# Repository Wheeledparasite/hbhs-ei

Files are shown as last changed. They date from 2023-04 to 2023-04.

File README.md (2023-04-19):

# Huntington Beach High School - Automotive Engineering Club - 2022 Archive
HBHS 2022 Energy Invitational Repo

## Archived repository for 2022 Energy Invitational Competition
The [HBHS Automotive Engineering Club](https://hbhs.bytethug.com/) competed at the 2022 [UCI Energy Invitational](https://vitallink.org/program/energy-invitational/) competition for the first time.

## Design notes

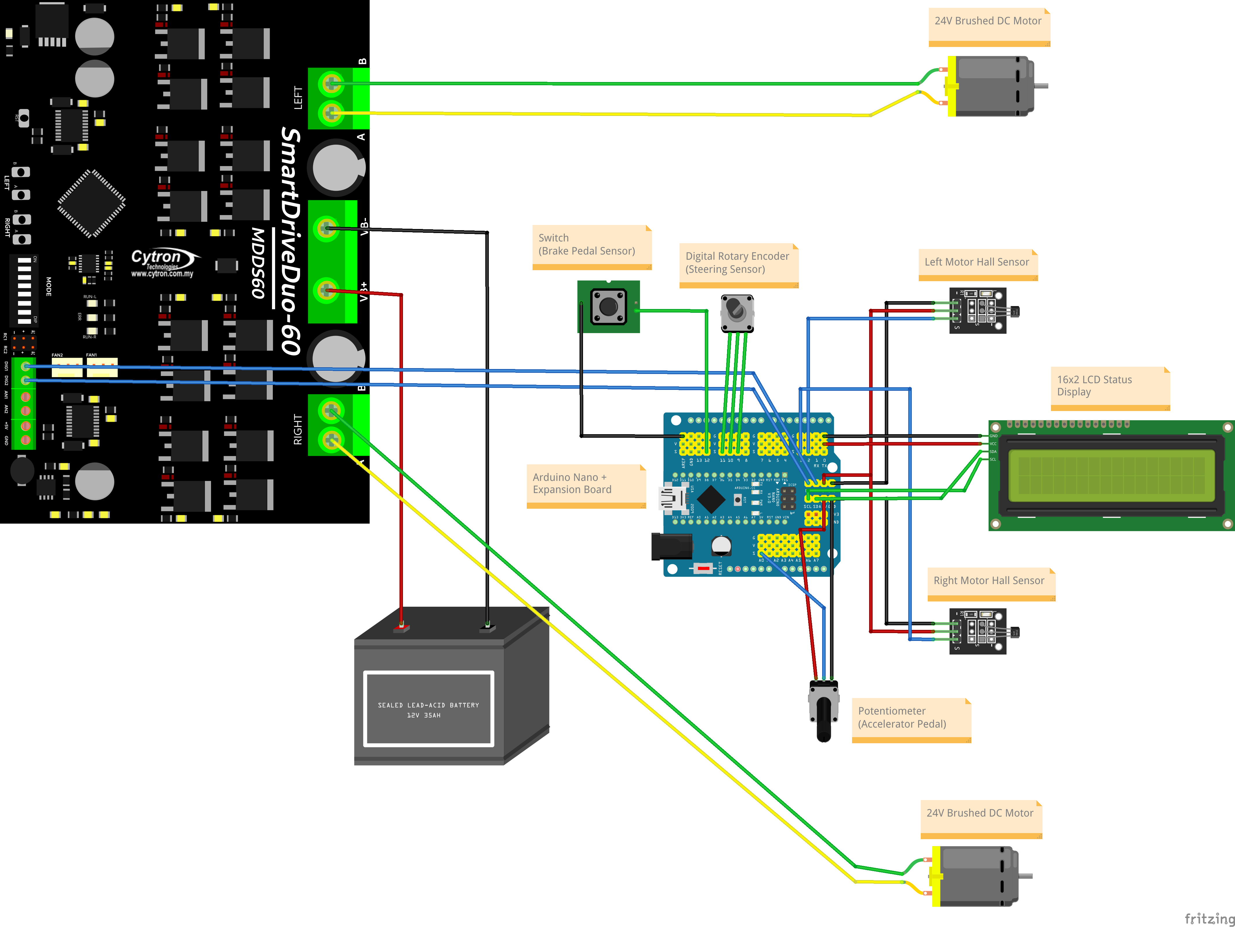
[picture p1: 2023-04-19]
schematics/schematic_v2.png

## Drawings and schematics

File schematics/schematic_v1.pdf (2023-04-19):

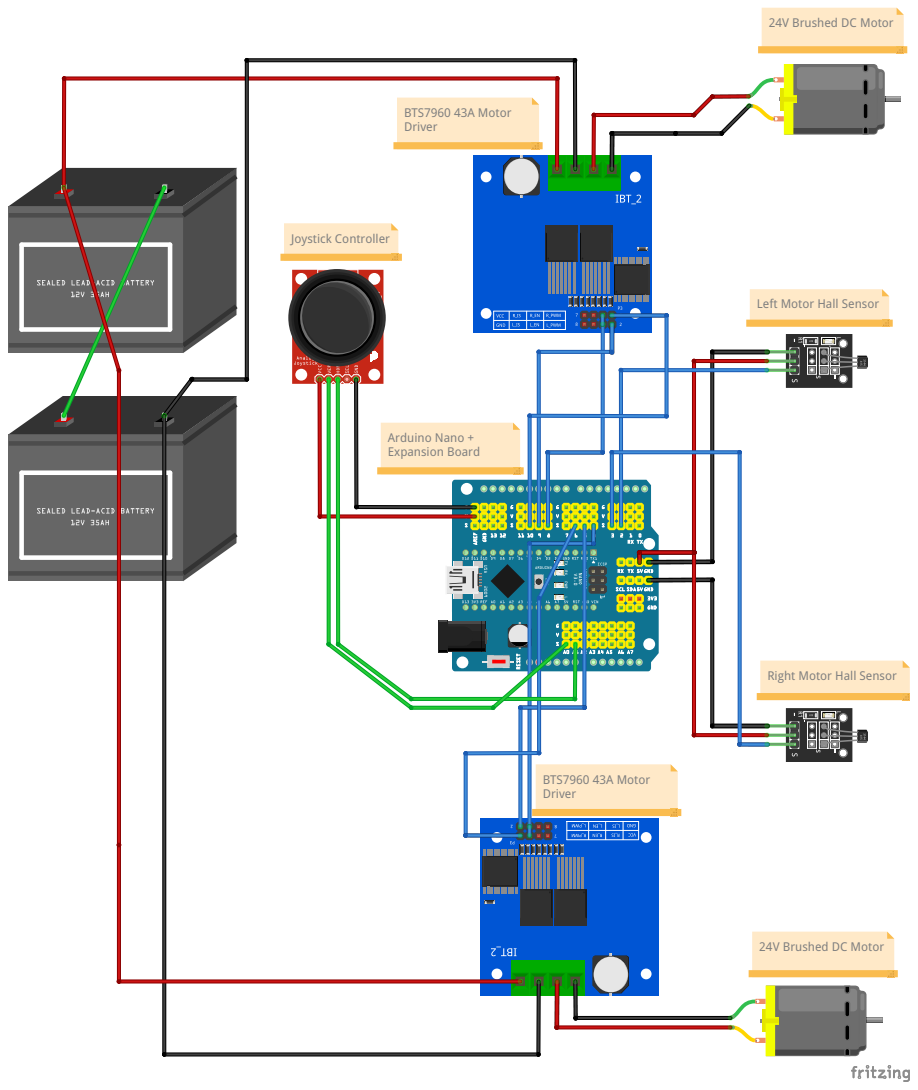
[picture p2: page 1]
BTS7960 43A Motor Driver; Arduino Nano + Expansion Board; Joystick Controller

24V Brushed DC Motor

Left Motor Hall Sensor

Right Motor Hall Sensor

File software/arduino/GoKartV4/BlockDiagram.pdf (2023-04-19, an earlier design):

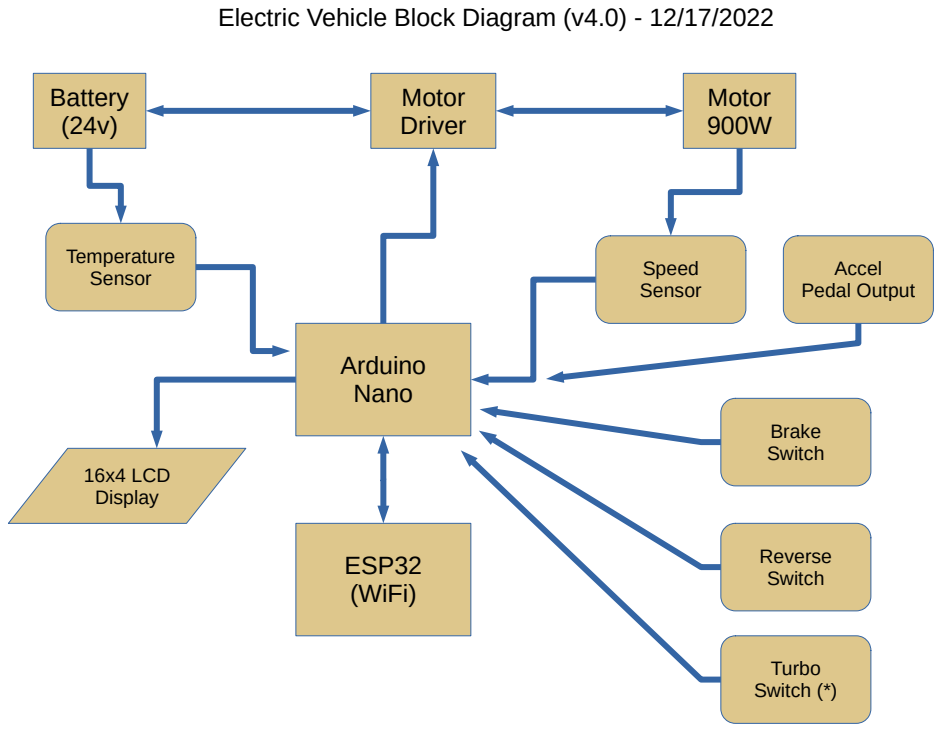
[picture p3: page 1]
Motor; Driver; Battery; Arduino; Nano; 16x4 LCD; Display; Speed; Sensor; Temperature; ESP32 (WiFi); Accel; Pedal Output; Brake; Switch; Reverse; Turbo; Switch (*)

Electric Vehicle Block Diagram (v4.0) - 12/17/2022

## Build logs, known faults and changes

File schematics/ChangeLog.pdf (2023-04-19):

Electronics Changelog

Version 1.0
- 16Mhz Arduino NANO
- 3 Hardware Timers (Timer0, Timer1 and Timer2)
- 1 UART (serial port)
- 6 PWM Pins (8-bit)
- 2 Interrupt Pins (Pin 2 & Pin 3)
- 2 Kb RAM
- 32 Kb Flash ROM
- (2) BTS7960 43A Motor Drivers
- Input from PS2 Style Joystick
- Hall Effect Sensors for wheel encoders (speed sensor)

Limitations of Version 1.0 Hardware
After building the 1.0 electronics test platform, we quickly determined there were some limitations of using such a slow 8-bit processor. First, because each of the BTS7960 motor drivers required 2 PWM signals, we needed a total of 4 PWM outputs. Using 4 PWM pins on the Arduino Nano meant that both TIMER0 and TIMER1 were being used to generate PWM signals and we only had TIMER2 left. We are using Timer2 set to 500ms to average the wheel encoder counts. Also, we have two HALL effect sensors we are using to measure wheel speed, these use up both Interrupt pins, leaving us with no free external interrupt pins in case we want to measure something else using interrupts. Two PID controllers manage motor speed based upon user input and measured speed.

Version 2.0:
- 16Mhz Arduino NANO
- 3 Hardware Timers (Timer0, Timer1 and Timer2)
- 1 UART (serial port)
- 6 PWM Pins (8-bit)
- 2 Interrupt Pins (Pin 2 & Pin 3)
- 2 Kb RAM
- 32 Kb Flash ROM
- (1) Cytron SmartDuo 60A Dual Channel Motor Driver (supports UART)
- Input from Accelerator Pedal + Steering Wheel
- (2) Temperature Sensors
- Hall Effect Sensors for wheel encoders (speed sensor)

Notes on Version 2.0 Hardware
The biggest change to this revision is the change from the generic motor drivers in V1 to the Cytron 60A Dual Driver in V2. This new motor driver allows serial communication (UART), allowing us to free up another TIMER in the Arduino, by removing the need for PWM, which will allow us to smoothly apply acceleration and deceleration, preventing the jerky movements we experienced in Version 1.0.

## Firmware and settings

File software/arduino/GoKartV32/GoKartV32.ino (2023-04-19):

/*
 * Author: Lucas Ruebsamen
 * Date: December 28, 2021
 * 
 * Version 1.1 - Updated Jan 14, 2022
 * Version 1.4 - Updated Feb 9, 2022
 * Version 3.0 - Updated March 16, 2022
 * Version 3.1 - Updated April 20, 2022
 * 
 * Changelog:
 * 1.0 - Original Version using Differential Steering
 * 1.1 - Remove reverse ability
 * 1.2 - Interrupt to count wheel rotation sensors (hall effect sensor)
 * 1.3 - Implement PID motor control
 * 1.4 - 500ms Timer2 interrupt to average wheel encoder counts.
 * 3.0 - Move to Cytron Driver board (serial) and steering encoder
 * 3.1 - Brake on Startup (Safety Feature)
 * 3.2 - Soft Acceleration
 * 
 * Notes: Differential steering control using two BTS7960 motor drivers
 *        driving two 250W Scooter motors.
 * 
 * Differential Steering Library: https://github.com/edumardo/DifferentialSteering
 * LCD Library: https://github.com/mrkaleArduinoLib/LiquidCrystal_I2C
 * PID Lbirary: https://github.com/imax9000/Arduino-PID-Library
 */

// SmartDriveDuo-60 Simplied Serial Mode (115200 baud) DIP SW SETTINGS:
// 11011100

/*
 * Timer0 - used for millis() micros() delay()… and is on pin 5, 6
 * Timer1 - 16bit timer is on pin 9, 10
 * Timer2 - 8bit timer is on pin 3, 11
 * 
 */

#include <Wire.h> 
#include <LiquidCrystal_I2C.h>
//#include "QuickPID.h"
//#include <MsTimer2.h>
//#include "DifferentialSteering.h"
#include <Encoder.h>

//#define PIDCONT

// PWM PINS on NANO: 3,5,6,9,10,11
// INTERRUPT PINS ON NANO: 2,3

// STEERING SENSOR (Rotary Encoder)
const uint8_t STEER_A = 7;
const uint8_t STEER_B = 8;
const uint8_t STEER_SW = 4;

//Pedal sensor pin
const uint8_t PEDAL = A0;

//turbo pin
const uint8_t TURBO = 9;

//power switch
const uint8_t POWER = 6;

//direction switch
const uint8_t DIRSW = 5;

//brake light
const uint8_t BRAKELIGHT = 10;

// differential steering
//const int brakeThreshold = 0;
//const int fPivYLimit = 32;  // 0 - 127 (A greater value will assign more of the joystick's range to pivoting) - default 32
//DifferentialSteering DiffSteer;

// instantiate our objects
LiquidCrystal_I2C lcd(0x27,16,2);  // set the LCD address to 0x27 for a 16 chars and 2 line display
Encoder steerEncoder(STEER_A, STEER_B);

const unsigned int sampleTime = 256;  // LCD UPDATE INTERVAL
const unsigned int accelTime = 500;   // ACCEL UPDATE INTERVAL
unsigned long lastMillis = 0;
unsigned long lastMillisAccel = 0;
volatile uint16_t avgLeft = 0;
volatile uint16_t avgRight = 0;
int pedalPos;
int desiredPedalPos = 0;

// Update Acceleration
void updateAccel()
{
  if (desiredPedalPos < pedalPos) {
    pedalPos = desiredPedalPos;
  } else {
    int diff = ceil( ((float)(desiredPedalPos - pedalPos))*(0.1f) );

    if (pedalPos > 30) {
      diff = 1; // slow down acceleration at top speed.
    }
    pedalPos += diff;
    if (pedalPos > desiredPedalPos) {
      pedalPos = desiredPedalPos;
    }
  }
}

// Run Once - Setup
void setup()
{
  Serial.begin(115200);
  // setup pins for speed sensors
  //pinMode(R_SEN, INPUT);
  //pinMode(L_SEN, INPUT);

  // pin for rotary switch
  pinMode(STEER_SW, INPUT_PULLUP);

  // setup pin for analog accelerator pedal
  pinMode(PEDAL, INPUT);
  pinMode(TURBO, INPUT_PULLUP);

  // setup pin for Power Switch
  pinMode(POWER, INPUT_PULLUP);

  pinMode(DIRSW, INPUT_PULLUP);
  pinMode(BRAKELIGHT, OUTPUT);

  // set initial speed to 0 for motor driver
  Serial.write(0b01000000);
  Serial.write(0b11000000);
  pedalPos = 0;
  desiredPedalPos = 0;
  
  lcd.init();                      // initialize the lcd 
  lcd.backlight();
  lcd.clear();
  lcd.print("GoKart v3.2");
  lcd.setCursor(0,1);
  lcd.print("Lucas Ruebsamen");
  delay(1000);
  lcd.clear();
  //DiffSteer.begin(fPivYLimit);
}

long positionSteering = -999;
bool turboMode = false;
bool powerSwitch = false;
uint8_t direction = 1;  // current direction -- 1 is forward, 0 is reverse
uint8_t dirSwitch = 1;  // direction switch

// 0 = 0v to 1023 = 5v
// we need 0 - 127 
void loop()
{
  char sVal[5];

  // read steering encoder
  positionSteering = steerEncoder.read();

  // reset encoder on button push
  if(digitalRead(STEER_SW) == LOW) {
    steerEncoder.write(0);
  }

  // read accelerator pedal (185 - 855)
  // Note: Cytron Driver - Serial mode takes 6 bit speed input (0 - 63)
  desiredPedalPos = analogRead(PEDAL);
  desiredPedalPos = map(desiredPedalPos, 186, 855, 0, 63);

  // brake enabled
  if (desiredPedalPos <= 2) {
    desiredPedalPos = 0;
    digitalWrite(BRAKELIGHT, HIGH);
    direction = dirSwitch;
  } else {
    digitalWrite(BRAKELIGHT, LOW);
  }

  if (desiredPedalPos >= 63) {
    desiredPedalPos = 63;
  }
  
  //read dir switch
  if (digitalRead(DIRSW) == LOW) {
    dirSwitch = 1;  // forward
  } else {
    dirSwitch = 0; // reverse
  }
  
  // read turbo switch
  if (digitalRead(TURBO) == LOW) { 
    turboMode = true;
  } else {
    desiredPedalPos = floor(desiredPedalPos * 0.65);
    turboMode = false;
  }

  if (digitalRead(POWER) == LOW) {
    powerSwitch = true;
  } else {
    powerSwitch = false;
  }

  // if we want to go slower, immediately reduce speed
  if (desiredPedalPos < pedalPos) {
    pedalPos = desiredPedalPos;
  }
  
  // take pedal position and steering position and compute motor output

  // compute left motor
  unsigned char leftVal = pedalPos & 0b00111111;
  leftVal = (leftVal | 0b00000000) | (direction << 6);
  // compute right motor
  unsigned char rightVal = pedalPos & 0b00111111;
  rightVal = (rightVal | 0b10000000) | (direction << 6);

  // set motor direction
  //if (direction) {
  //  leftVal = leftVal | (1 << 6);
  //  rightVal = rightVal | (1 << 6);
  //}

  // Write serial data to motor driver
  if (powerSwitch) {
    // power is on, control motors
    Serial.write(leftVal);
    Serial.write(rightVal);
  } else {
    // power is off, motors disabled
    Serial.write(0b01000000);
    Serial.write(0b11000000);
  }

  // HANDLE ACCELERATION UPDATES HERE
  if (millis() - lastMillisAccel >= accelTime) {
    updateAccel();
    lastMillisAccel = millis();
  }

  // HANDLE LCD UPDATES HERE
  if (millis() - lastMillis >= sampleTime) {
    // 500ms has elapsed since last lcd update, time to update again
    lcd.setCursor(0,0); // col 0, row 0
    if (powerSwitch) {
      lcd.print("S: ");
      sprintf(sVal, "%+04d", (int)positionSteering);
      lcd.printstr(sVal);
  
      lcd.setCursor(8,0); // col 0, row 1
      lcd.print("P: ");
  
      if (turboMode == true) {
        sprintf(sVal,"%+04d*", (int)pedalPos);
      }else {
        sprintf(sVal,"%+04d ", (int)pedalPos);
      }
      lcd.printstr(sVal);
  
      lcd.setCursor(0,1); // col 0, row 1
      lcd.print("L: ");
      //lcd.print(xValue);
      sprintf(sVal,"%+04d", (int)avgLeft);
      lcd.printstr(sVal);
  
      lcd.setCursor(8,1);   // col 8, row 1
      lcd.print("R: ");
      sprintf(sVal,"%+04d", (int)avgRight);
      lcd.printstr(sVal);
    } else {
      lcd.print("Pow     Off");
    }
    lastMillis = millis();
  }
}
